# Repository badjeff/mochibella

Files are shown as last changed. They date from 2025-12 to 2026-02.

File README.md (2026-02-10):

# mochibella

An open source trackball.

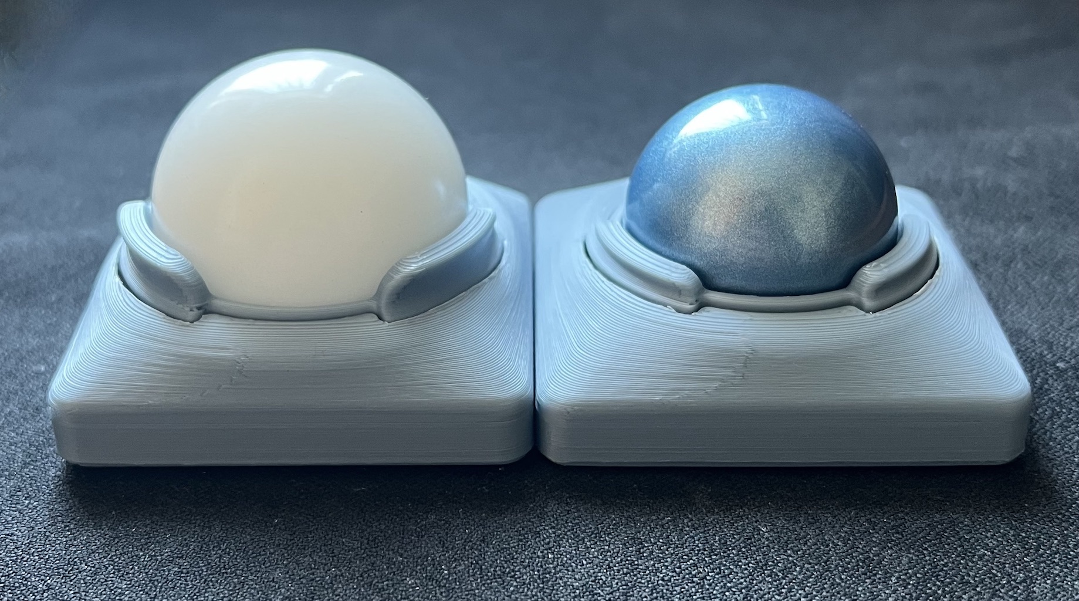
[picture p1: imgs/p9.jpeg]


*Figure 1: PLA case; 40mm(left) & 34mm(right)

### Design Principles
- Symmetrical design; Must allow switch hands in anytime
- Fingerball; Supreme precision with 40mm/34mm trackball; Must have control surface for 3+ fingers (>3/5 surface is available)
- Never need to lift off any finger from the ball
- Push-to-click; Utilize buttons as pivot point
- Twist-to-scroll; Utilize dual sensor
- Low profile. With my slim breakout pcb. https://github.com/badjeff/paw3222-pcb
- Powered by [ZMK](https://github.com/zmkfirmware/zmk) => OSS, on-devie profiling, say no to (Logxtxxh|Razxx) eco-system
- No screws; Snapfit only; Must be easy & fast to repair broken clips
- Wireless; Long battery life
- Silent tactile switches

### Gallery

<p float="left">
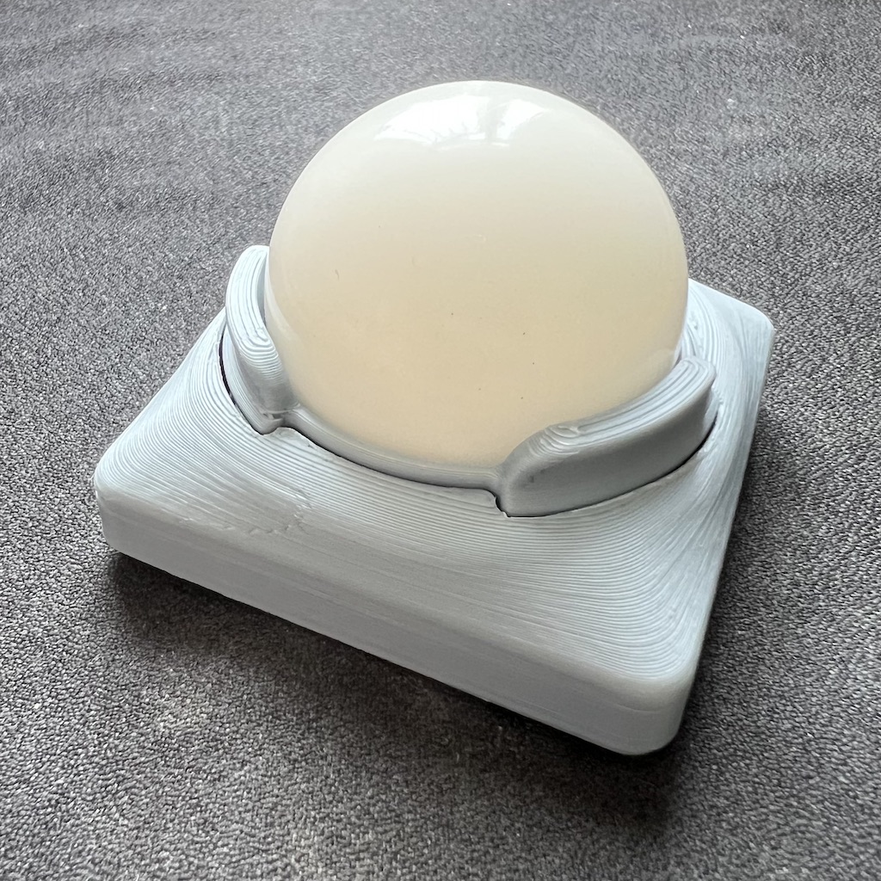
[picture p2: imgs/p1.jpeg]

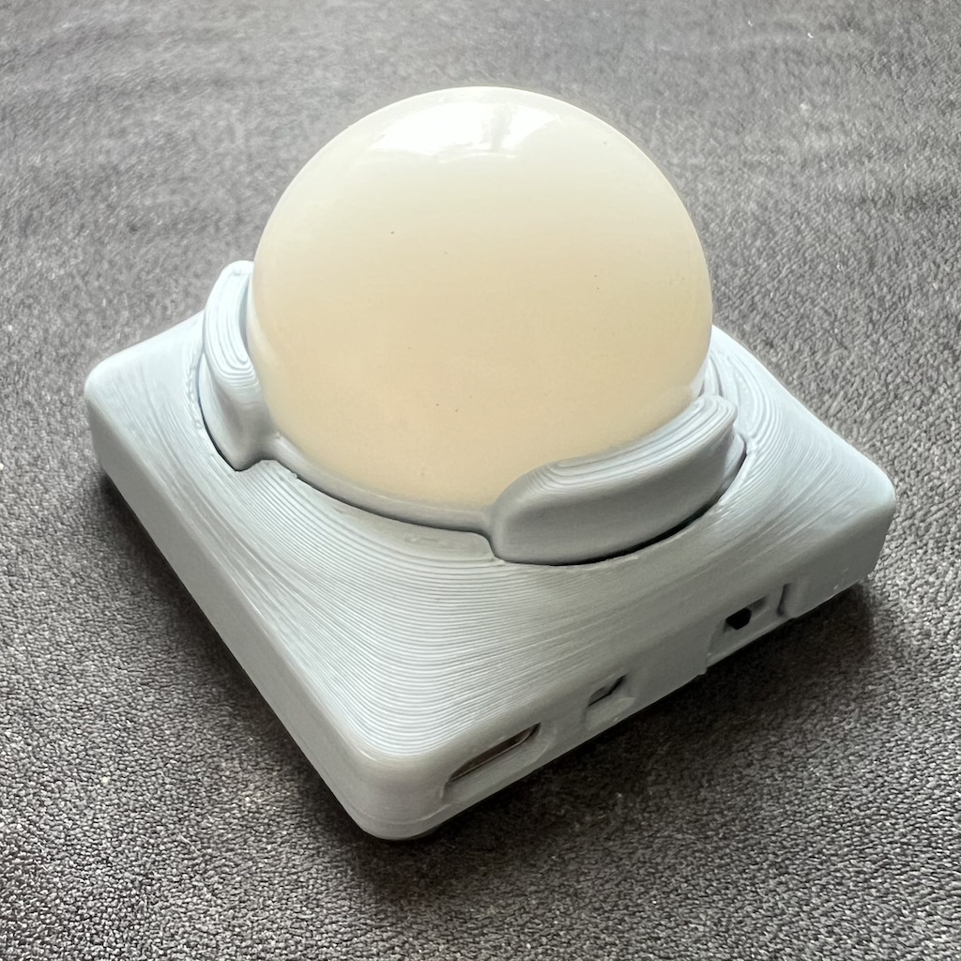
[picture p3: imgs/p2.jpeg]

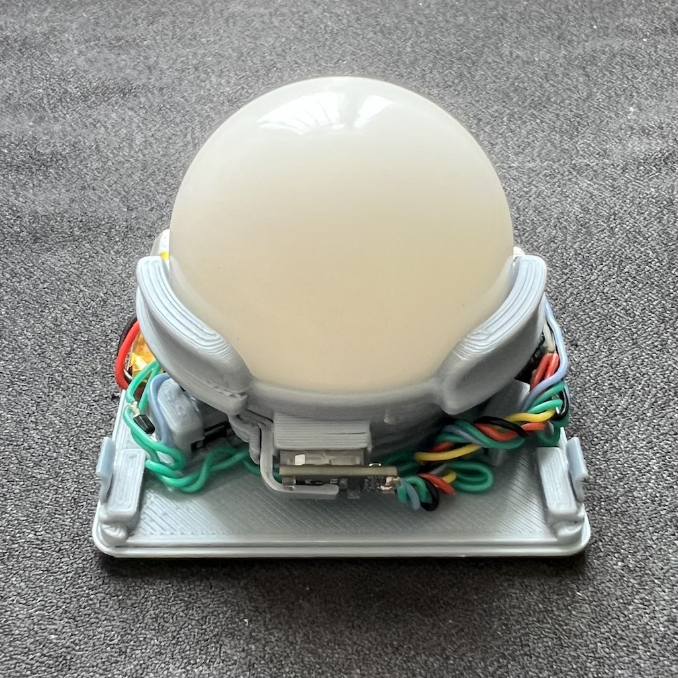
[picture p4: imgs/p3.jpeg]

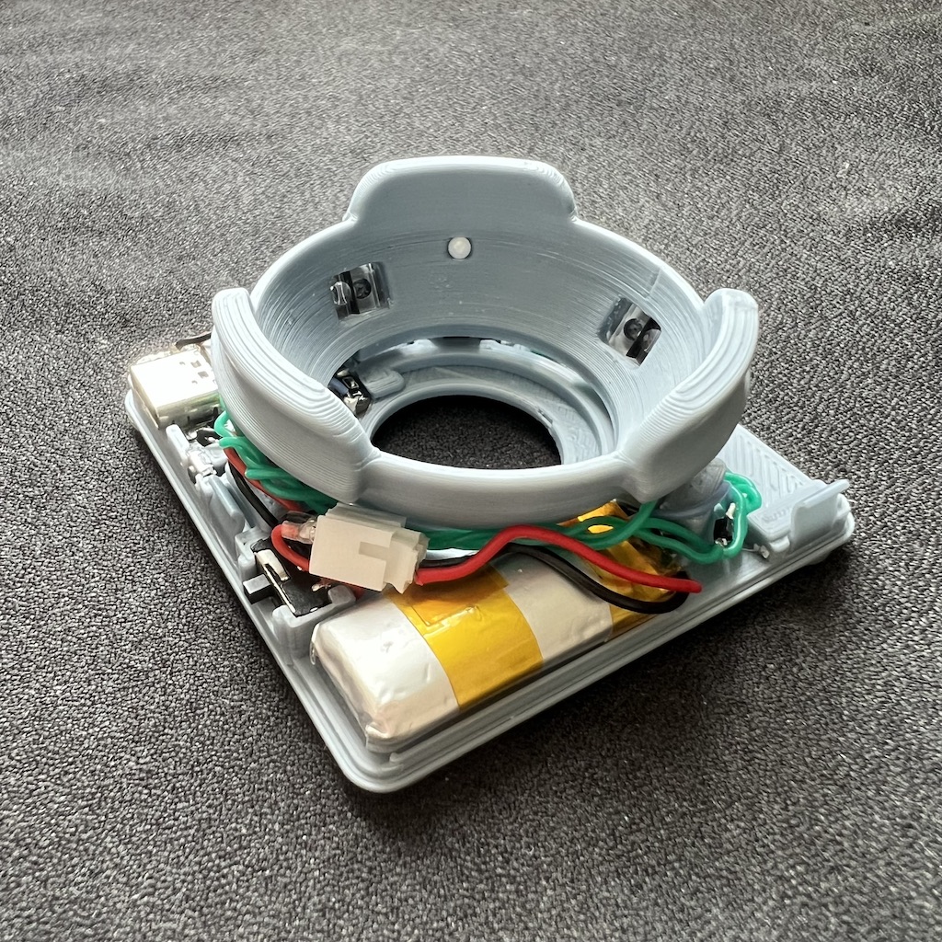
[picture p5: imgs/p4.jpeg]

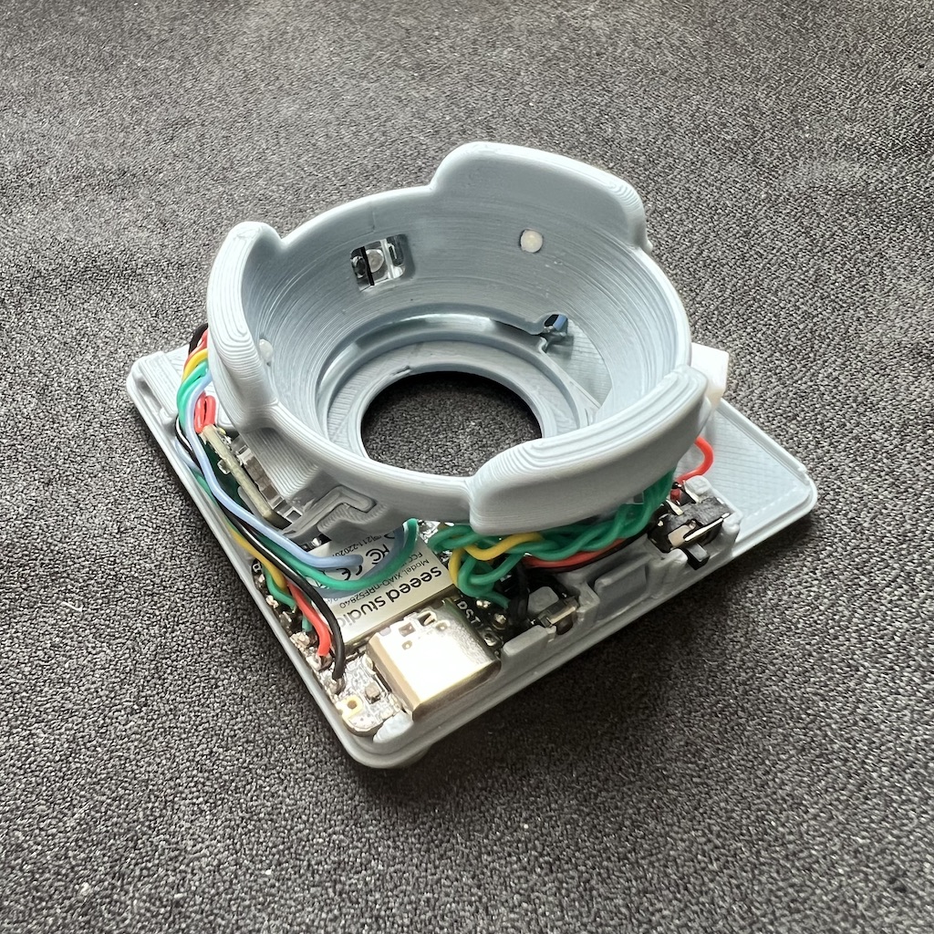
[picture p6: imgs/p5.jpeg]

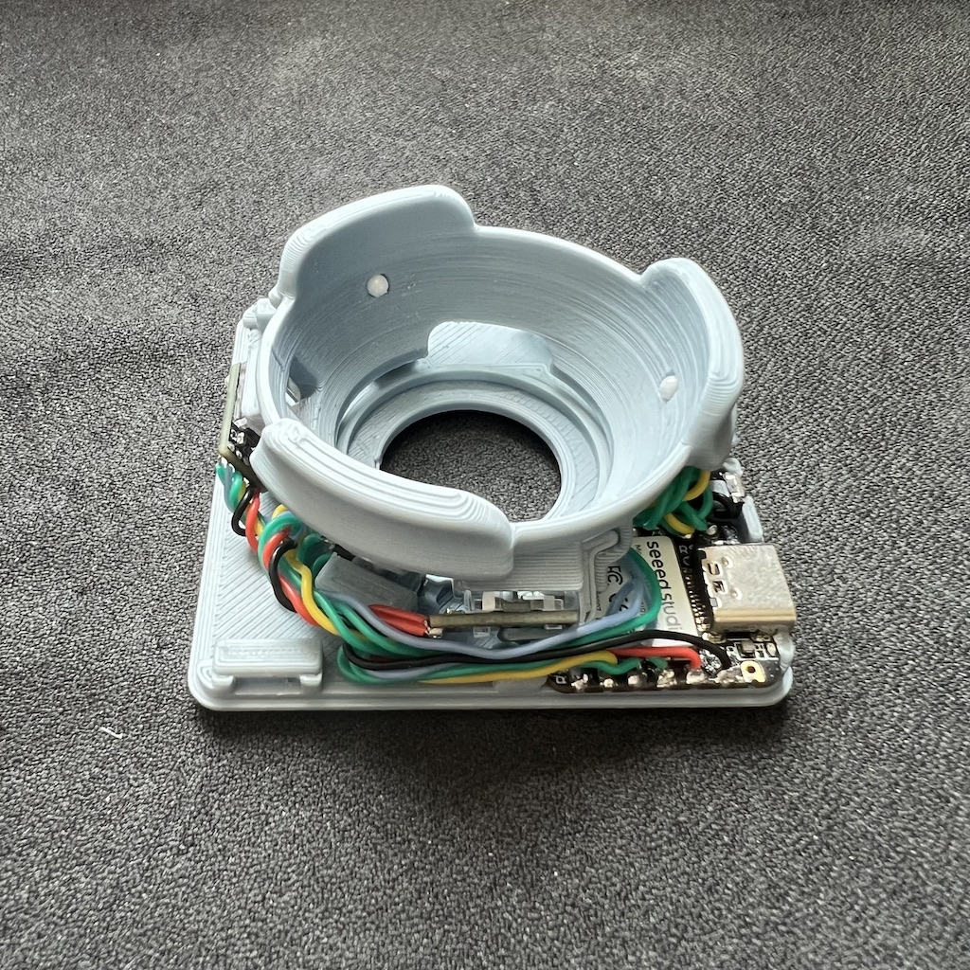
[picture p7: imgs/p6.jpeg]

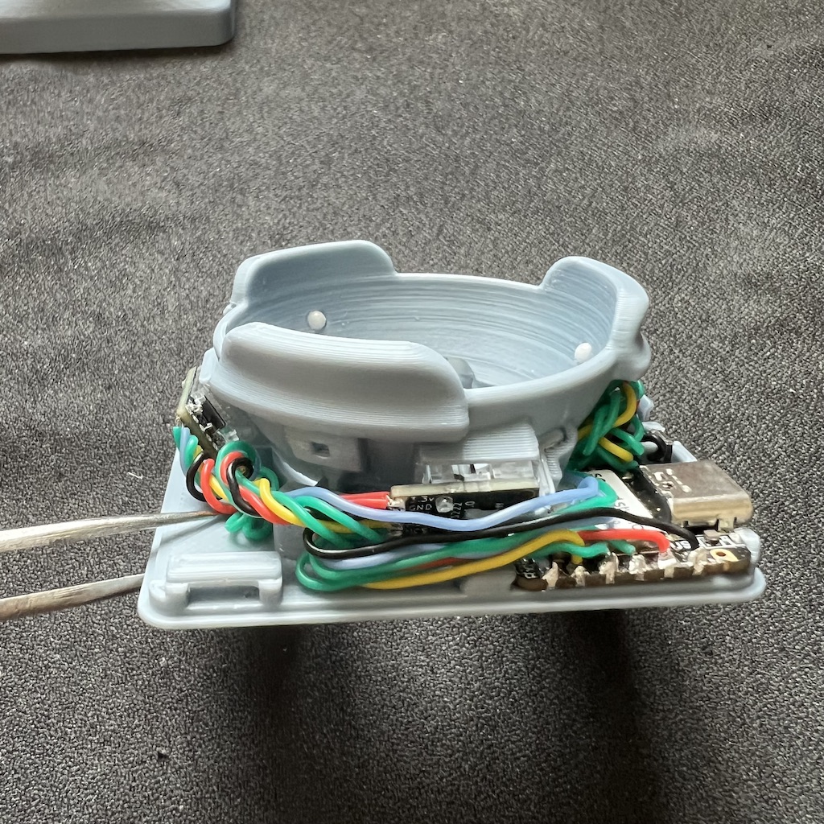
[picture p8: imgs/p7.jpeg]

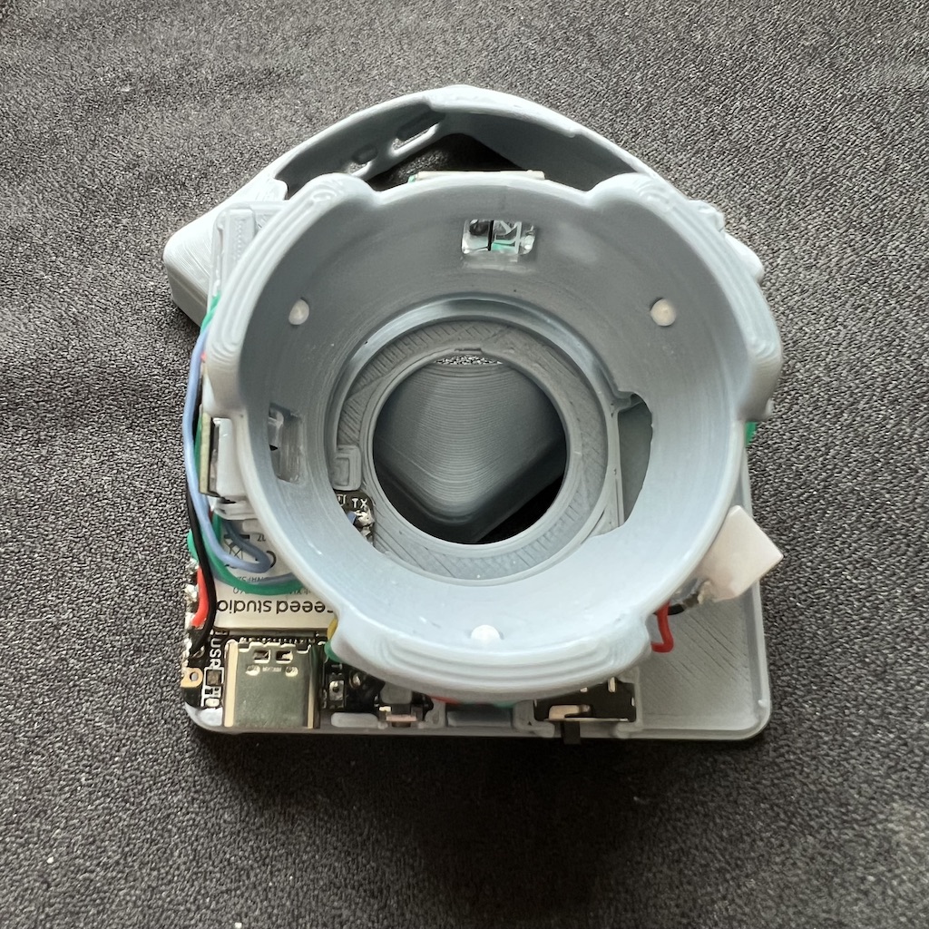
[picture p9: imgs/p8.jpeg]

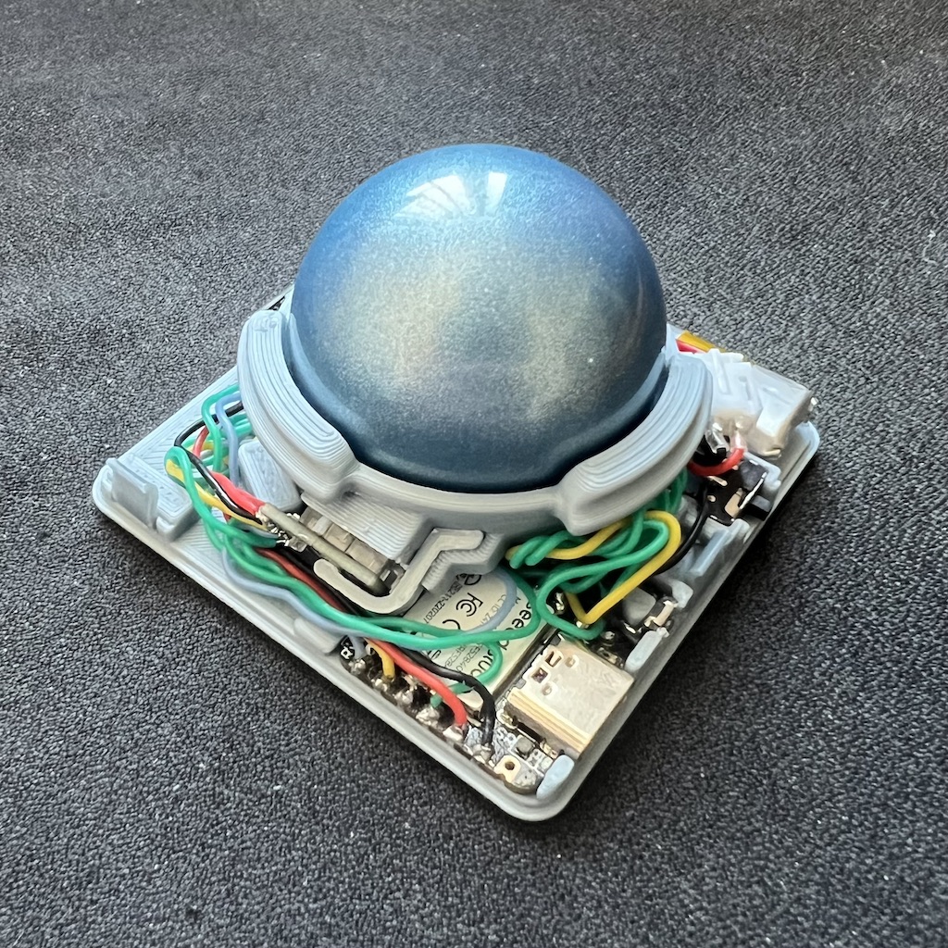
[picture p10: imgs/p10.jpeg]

</p>

<p float="left">
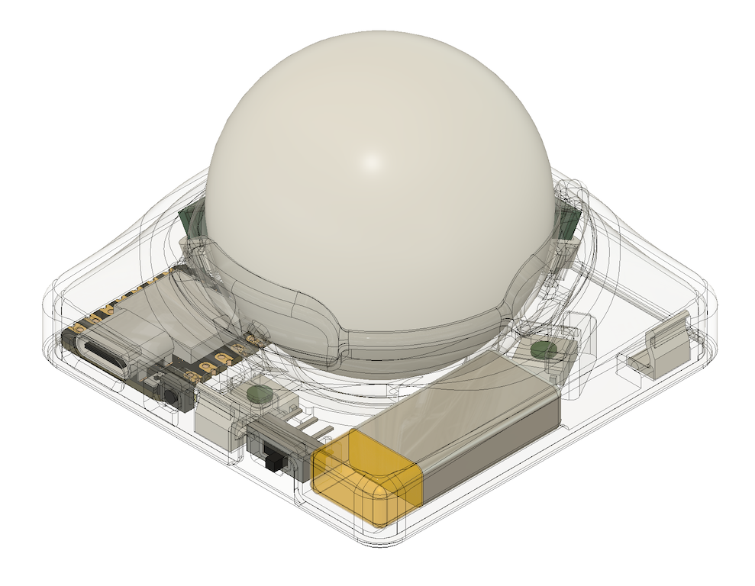
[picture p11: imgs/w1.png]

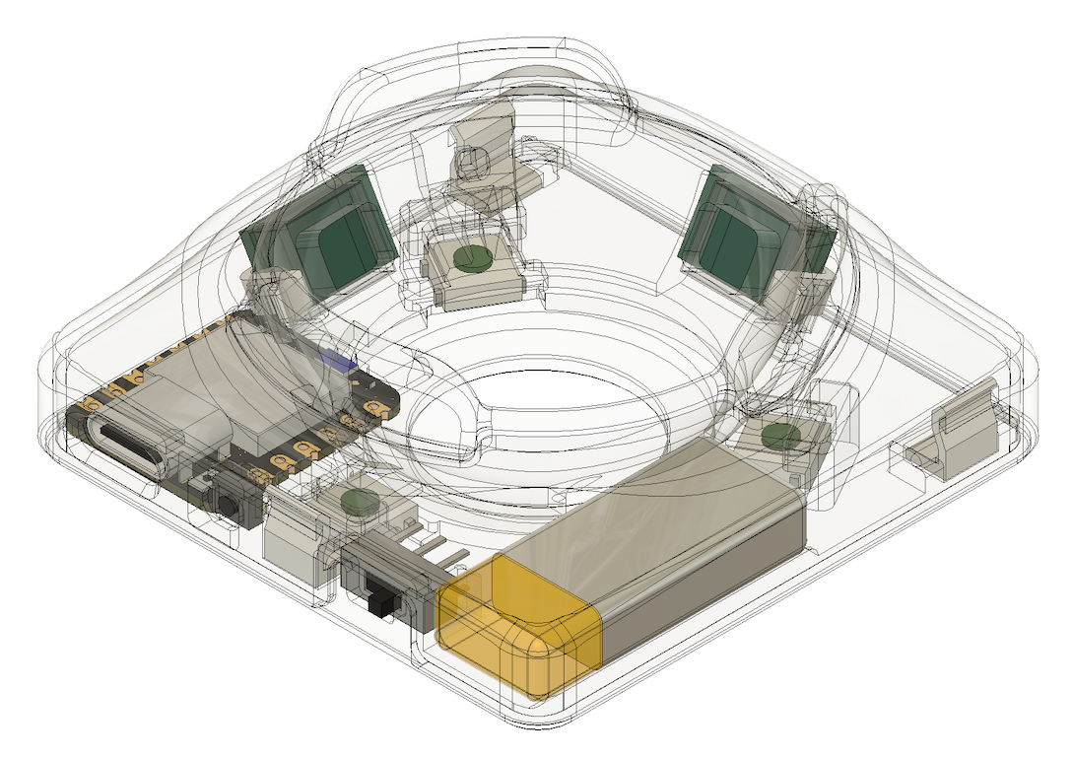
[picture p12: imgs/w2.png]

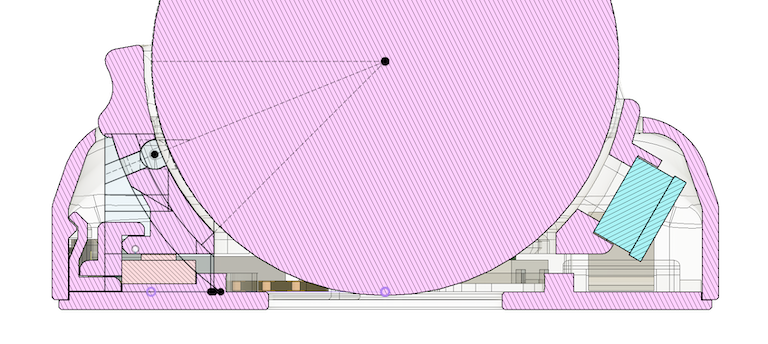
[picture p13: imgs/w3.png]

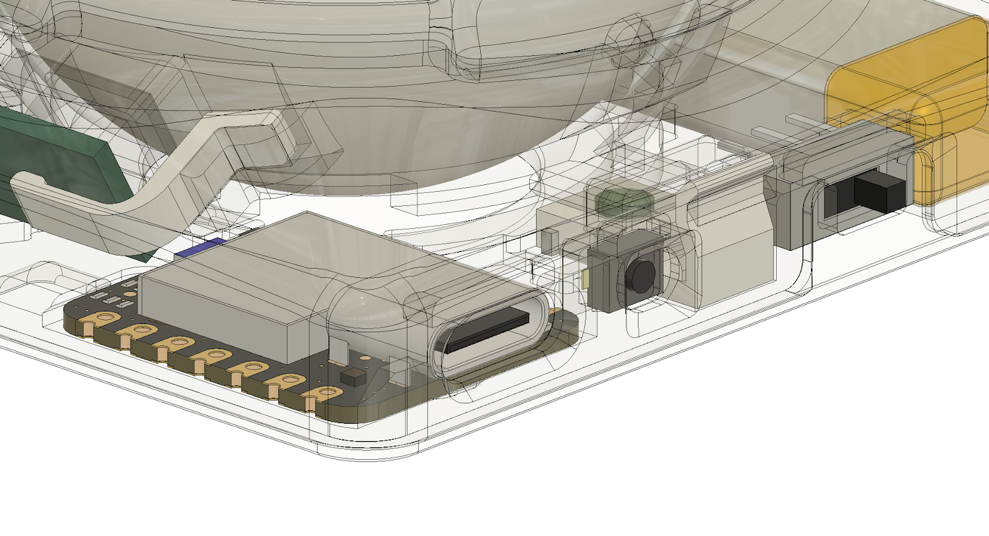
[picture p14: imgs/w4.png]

</p>

### Grip

Below diagram is showing the ideal finger grip points to use this trackball (40mm version). The pinky should rest on the desk and touching the side of the case.

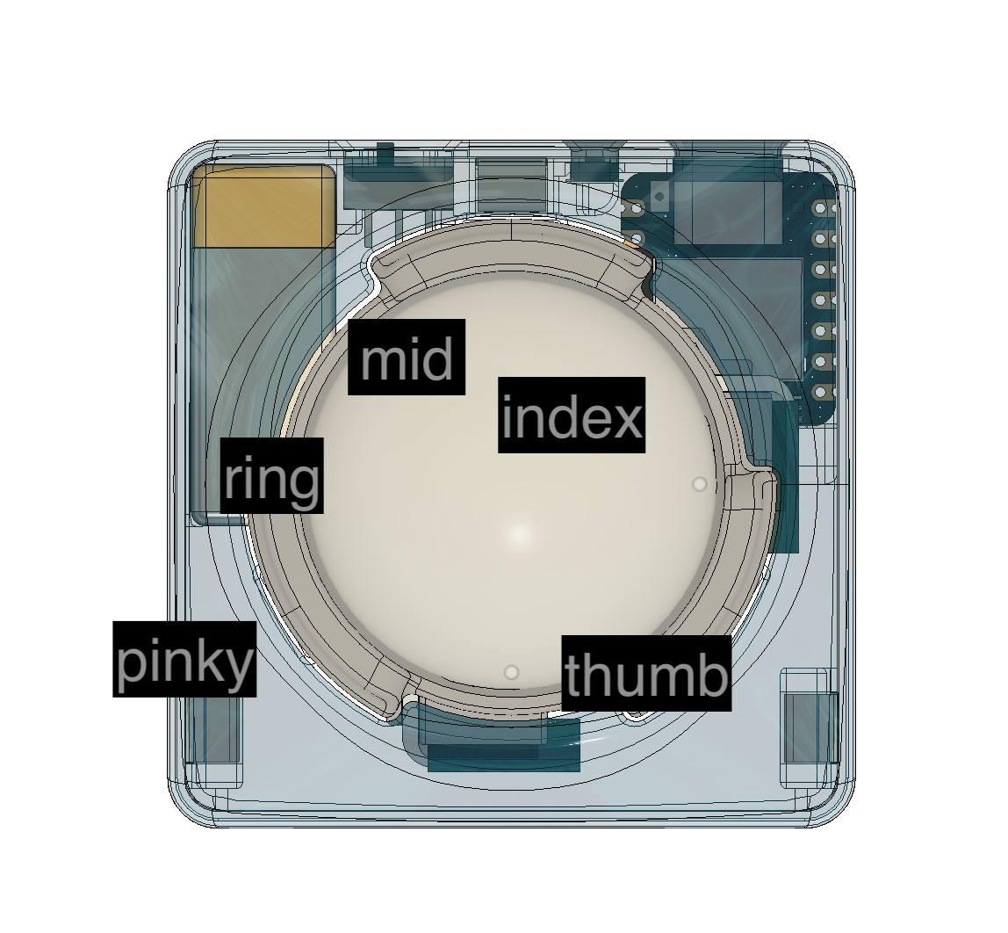
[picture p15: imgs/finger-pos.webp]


### BOM
|Unit|Item|
|-|-|
|1|Seeed Studio XIAO BLE (nRF52840)|
|2|PAW3222LU-TJDU Sensor with PNSR-015-RB3 Lens [Breakout Board](https://github.com/badjeff/paw3222-pcb)|
|1|40mm/34mm trackball. or, pom ball from ebay/aliexpress|
|3|6.4mm(W) Micro Switch. Huano Silent Grey 2.5mm(H), or APLS SKHUAKE010 2.5mm(H), or APLS SKRAAWE010 3.5mm(H)|
|3|1N4148W T4 SOD-123 Diode|
|1|MSK-1153 6 Pins Power Switch|
|1|3x4x2mm Tact Switch Turtle Switch|
|3|Static ceramic bearings; 2.5mm|
|1|601230 Lipo Battery (plus connector)|
|4|Non-Slip Silicone Sticker (>1mm thick)|
|1|28/26 AWG silicone wire|

### Building Guide / Tips

- NOT for beginner. Requiring experience of building at least one wireless keyboard on [ZMK](https://github.com/zmkfirmware/zmk).
- MUST have a funcation brain. Requiring to puzzling to assemble all parts together.
- NEED very good eyesight, and soldering skill (and tools)
- Weight of the trackball and actuation force of switches is corelated, it'd be adjusted in CAD file by moving its pivot position. My trackball used is ~44g(@40mm) and the micro switch is SKRAAWE010 (0.6N operating force). Simple physics.
- Choose the `base-{switch-height}mm.stl` file respectively for your switch option.
- Axis reading from dual sensor is mixed to report 3 degree of freedom in firmware. Some coefficients is cooked for twist-to-scroll in `mochibella-zmk-config`, not hardcoded in ZMK module.
- The firmware is cooked for low-latency HID trnasportation. e.g. USB, or dongle mode with [zmk-feature-split-esb](https://github.com/badjeff/zmk-feature-split-esb).

### Firmware

The ZMK firmware config repository can be find at [badjeff/mochibella-zmk-config](https://github.com/badjeff/mochibella-zmk-config).

## License

Available under the [CERN-OHL-P v2](/LICENSE) permissive license.

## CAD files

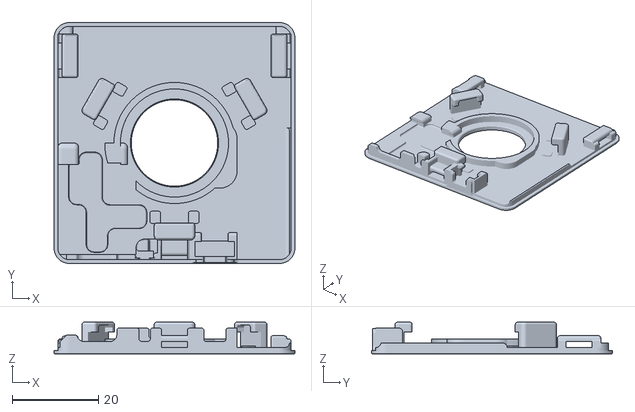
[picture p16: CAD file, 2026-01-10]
STLs/34mm/base-3.5mm.stl
55.8 x 55.8 x 7.35

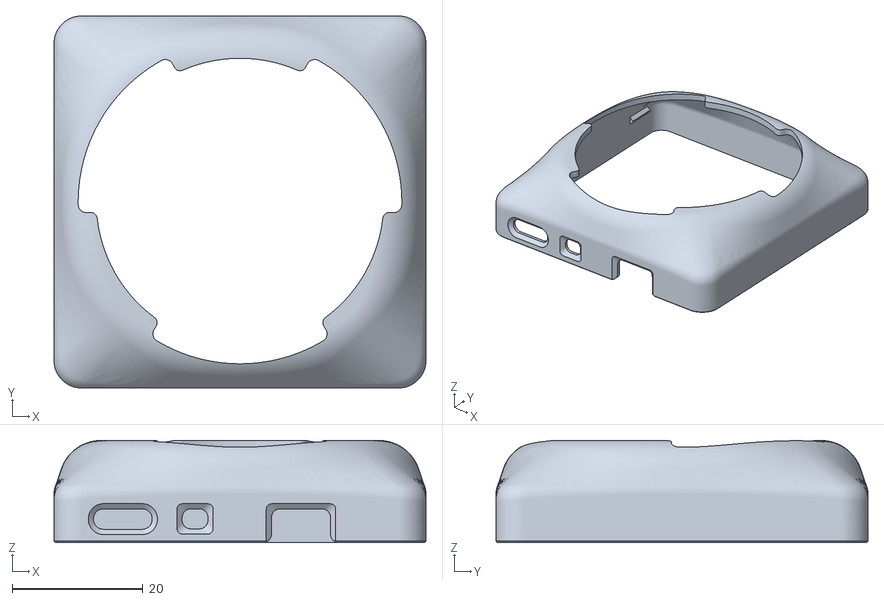
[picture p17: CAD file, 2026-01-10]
STLs/40mm/case.stl
57.0 x 57.0 x 15.6

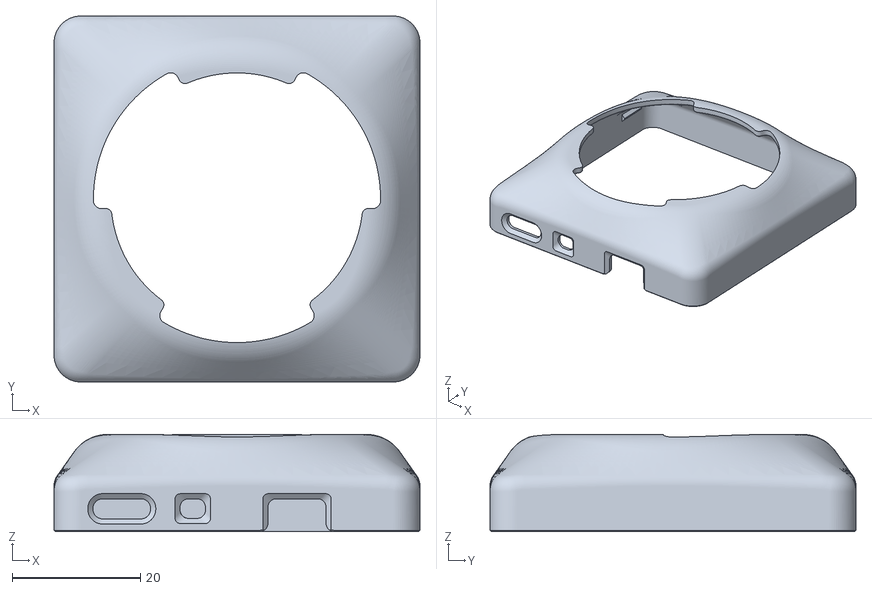
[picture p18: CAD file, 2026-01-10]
STLs/34mm/case.stl
57.0 x 57.0 x 15.1

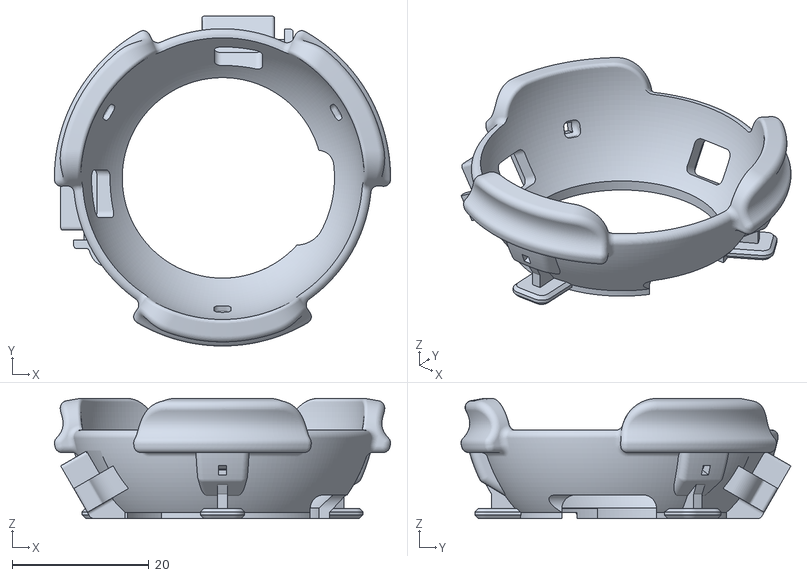
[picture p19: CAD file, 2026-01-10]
STLs/40mm/cup.stl
49.1 x 48.2 x 17.6

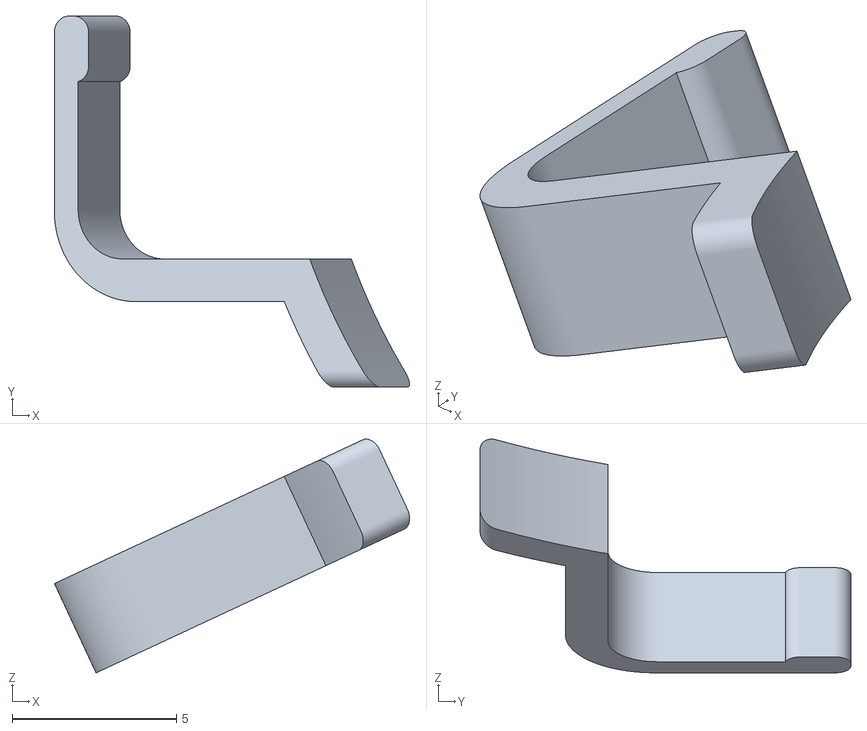
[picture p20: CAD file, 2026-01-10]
STLs/34mm/sensor clip.stl
10.8 x 11.3 x 7.12

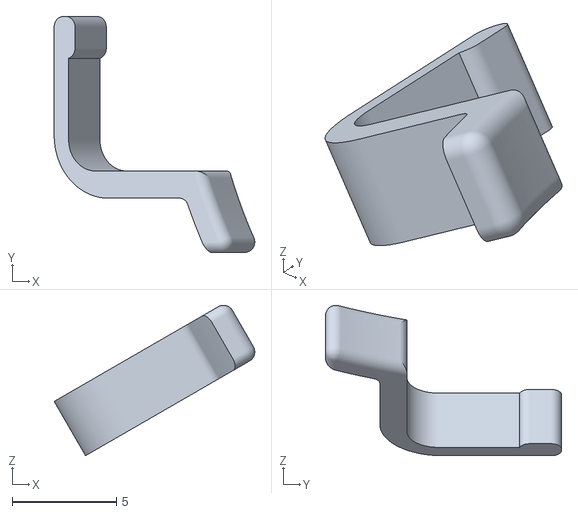
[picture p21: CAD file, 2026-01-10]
STLs/40mm/sensor clip.stl
9.61 x 11.3 x 7.20

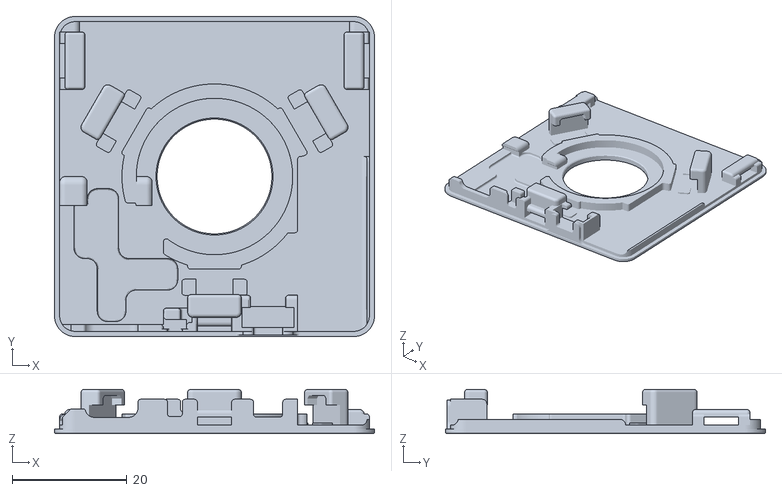
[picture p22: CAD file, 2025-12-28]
STLs/40mm/base-3.5mm.stl
55.8 x 55.8 x 7.75

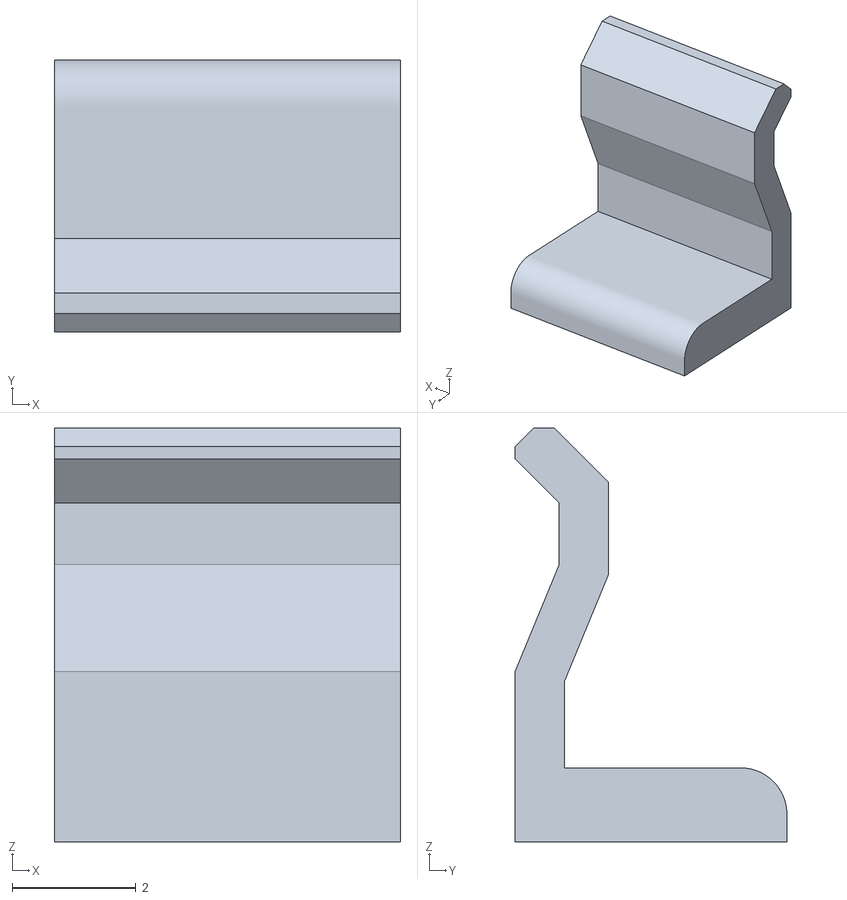
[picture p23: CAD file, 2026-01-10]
STLs/34mm/case clip.stl
5.60 x 4.40 x 6.70

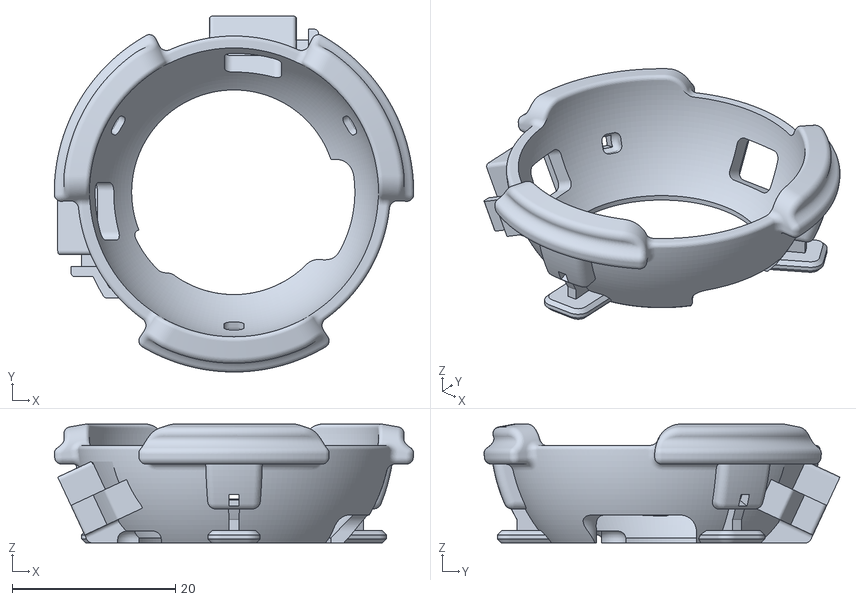
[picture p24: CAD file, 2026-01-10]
STLs/34mm/cup.stl
44.0 x 43.6 x 14.6

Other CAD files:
STLs/34mm/base-2.5mm.stl
STLs/40mm/base-2.5mm.stl
STLs/40mm/case clip.stl

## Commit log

2025-12-28 init commit
    [base-2.5mm.stl, base-3.5mm.stl, case clip.stl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]
2025-12-28 update switch option in README.md
2025-12-28 Fix trackball weight and switch actuation force description
    Corrected weight and actuation force details for trackball and switch.
2025-12-28 Fix micro switch operating force in README
    Corrected the operating force specification for the micro switch in the README.
2026-01-10 add 34mm mod up
    [base-2.5mm.stl, base-3.5mm.stl, case clip.stl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]
2026-02-10 add one more micro switch option
